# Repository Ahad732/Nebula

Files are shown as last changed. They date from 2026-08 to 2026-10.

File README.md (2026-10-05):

# RP2040 Devboard
I have made a devboard with RP 2040 microcontroller. It has 16 mb storage and its just like a raspberry pi pico but in my design. I had build it off a guide from macondo.I built it to learn hardware. This was my first hardware project for hackclub. It has a usb type C port that is used everywhere nowadays.

Features :
16 Mbit Storage    
Bootsel button  
Uses the popular RP2040 microcontroller    
Can be easily coded for custom projects and inovative ideas  
Open-source so anyone can use the design and order their board  
Has 2 leds, a power and a gpio led  

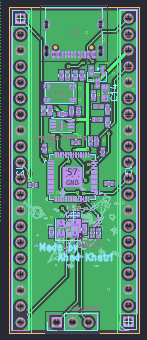
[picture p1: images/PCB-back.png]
  
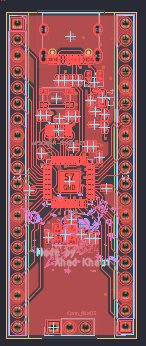
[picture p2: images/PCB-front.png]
  
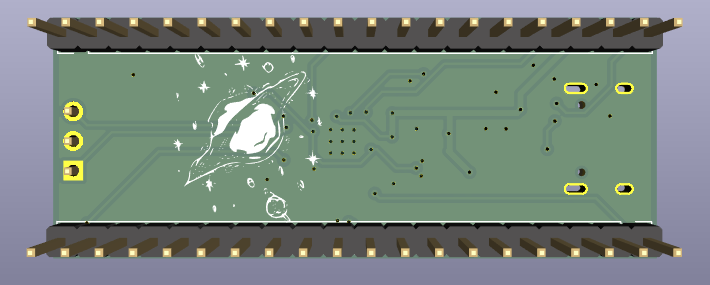
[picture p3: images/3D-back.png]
 
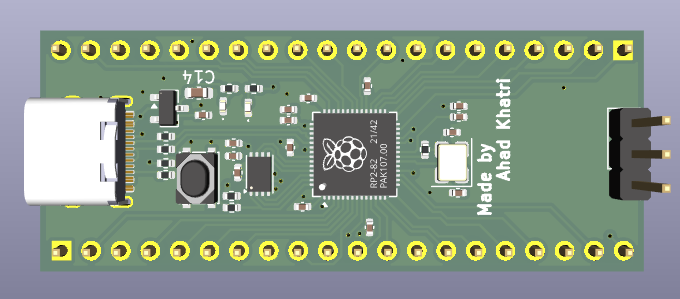
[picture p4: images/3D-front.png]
 
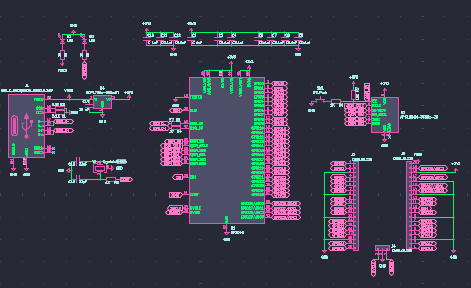
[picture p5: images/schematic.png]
schematic


|Designator |Footprint |Value |Quantity |Price |Link |
|---|---|---|---|---|---|
|C1_2, C1, C10 |402 |C 1uf |125 |0.1 |https://robu.in/product/cl05a105kq5nnwc-samsung-electro-mechanics-multilayer-ceramic-capacitors-mlcc-smd-smt-1uf-10-6-3v-x5r-1-0402/ |
|C11, C12, C3, C4, C5, C6, C7, C8, C9_2, C9|402 |C0.1uf |ALREADY HAVE |---------------------|https://robu.in/product/0402b104j100ct-walsin-smd-multilayer-ceramic-capacitor-general-purpose-0-1-%c2%b5f-10-v-0402-1005-metric-%c2%b1-5-x7r/ |
|C14 |603 |10 uF |ALREADY HAVE |---------------------|https://robu.in/product/tcc0603x5r106m100ct-cctc-smt-ceramic-capacitors-0603-x5r-106m10%c2%b5f%c2%b120-rated-voltage10v-thickness0-80mm-tape/ |
|C15, C16 |402 |33pF |30 |0.11 |https://robu.in/product/0402hq330j500nb-fh-smd-multilayer-ceramic-capacitor-33-pf-50-v-0402-1005-metric-%c2%b1-5-c0g/ |
|J1 |USB_C_Receptacle_XKB_U262-16XN-4BVC11 |USB_C_Receptacle_USB2.0_16P|ALREADY HAVE |---------------------|https://www.lcsc.com/product-detail/C393939.html?s_z=n_q_c393939&globalKeyword=c393939 |
|J2, J3 |PinHeader_1x20_P2.54mm_Vertical |Conn_01x20 |2 |DNP | |
|J4 |PinHeader_1x03_P2.54mm_Vertical |Conn_01x03 |1 |DNP | |
|R1, R2 |402 |5.1K |100 |0.11 |https://robu.in/product/rc0402fr-075k1l-yageo-smd-chip-resistor/ |
|R3, R4 |402 |27 |35 |0.12 |https://robu.in/product/0402wgj0270tce-uniohm-royal-ohm-62-5mw-thick-film-resistors-50v%c2%b1100ppm-%e2%84%83-%c2%b15-27%cf%89-0402-chip-resistor-surface-mount-rohs/|
|R5, R6, R7, R8 |402 |1K |30 |0.11 |https://robu.in/product/wr04x1001ftl-walsin-62-5mw-thick-film-resistors-50v-%c2%b1100ppm-%e2%84%83-%c2%b11-1k%cf%89-0402-chip-resistor-surface-mount-rohs/ |
|R7 |402 |10K |85 |0.11 |https://robu.in/product/rc0402fr-0710kl-yageo-res-thick-film-0402-10k-ohm-1-0-063w1-16w-%c2%b1100ppm-c-pad-smd-t-r/ |
|SW1 |Button_Switch_SMD:SW_SPST_PTS810 |SW_Push |5 |0.99 |https://robu.in/product/pts810sjg250smtrlfs-ck-3-2mm-2-5mm-round-button-50ma-standing-paste-4-2mm-spst-400gf-16v-smd-4p3-2x4-2mm-tactile-switches-rohs/ |
|U1 |QFN-56-1EP_7x7mm_P0.4mm_EP3.2x3.2mm |RP2040 |2 |1.33 |https://robu.in/product/raspberry-pi-rp2040/ |
|U2 |Winbond_USON-8-1EP_3x2mm_P0.5mm_EP0.2x1.6mm|APS1604M-3SQRx-ZR |2 |4.88 |https://www.lioncircuits.com/parts/IS25WP016D-JULE-TR |
|U4 |SOT-23 |MCP1700x-330xxTT |2 |1.05 |https://www.lioncircuits.com/parts/MCP1700T-3302E%2FTT |
|Y1 |Crystal_SMD_3225-4Pin_3.2x2.5mm |Crystal_GND24 |2 |1.23 |https://www.lioncircuits.com/parts/ECS-120-20-33-CKM-TR |
|D1, D2 |Led |402 |---------------------- |ALREADY HAVE |--------------------- |
| | | |Tools Required For Building|22.88 |https://robu.in/product/yihua-8858-v-hot-air-station-nozzles-stand/ |
| | | |PCB Cost + Shipping |9.29 | |
| | | |Parts Shipping |1.55 | |
| | | |Total |43.86 | |

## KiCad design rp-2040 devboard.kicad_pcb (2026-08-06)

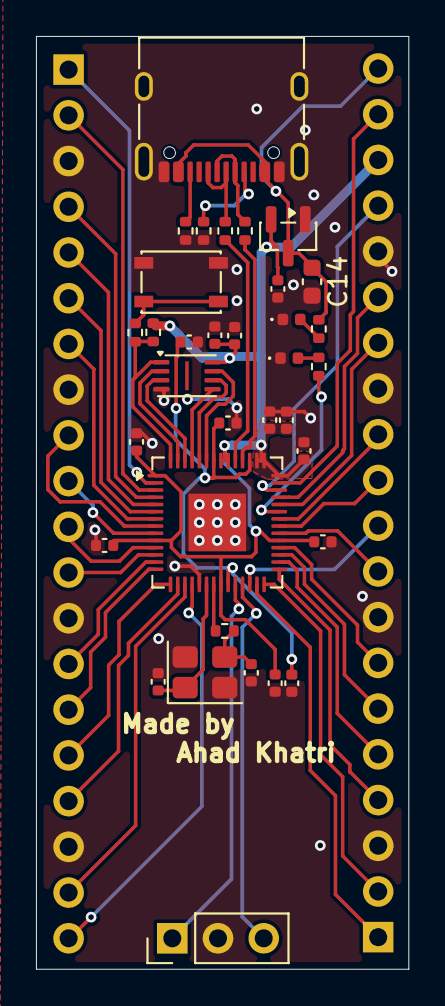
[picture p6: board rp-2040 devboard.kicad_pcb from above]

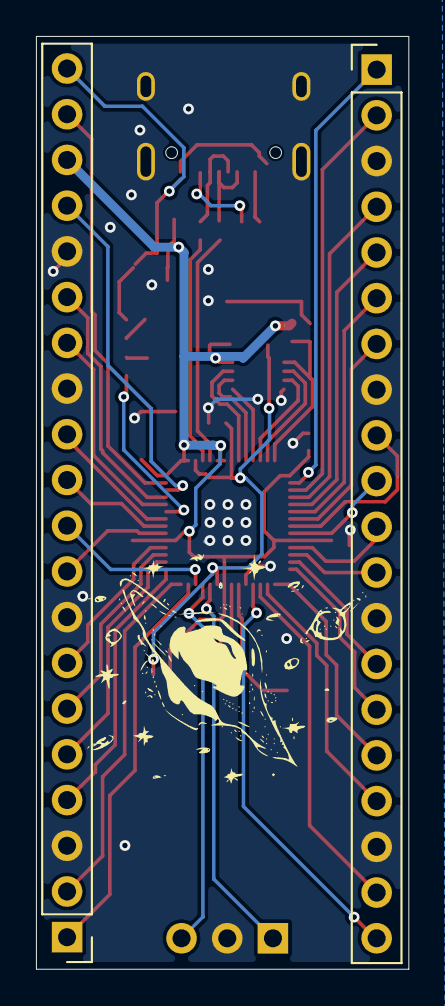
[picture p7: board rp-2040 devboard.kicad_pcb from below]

Board: 2 copper layers, 20.7 x 51.8 mm, 36 parts (2 on the bottom side), 55 nets.

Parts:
C1, C1#2, C10: C 1uf; C_0402_1005Metric
C3, C4, C5, C6, C7, C8, C9, C9#2, C11, C12: C0.1uf; C_0402_1005Metric
C14: 10 uF; C_0603_1608Metric
C15, C16: 33pF; C_0402_1005Metric
D1, D2: LED; LED_0402_1005Metric
J1: USB_C_Receptacle_USB2.0_16P; USB_C_Receptacle_XKB_U262-16XN-4BVC11
J2, J3: Conn_01x20; PinHeader_1x20_P2.54mm_Vertical
J4: Conn_01x03; PinHeader_1x03_P2.54mm_Vertical
R1, R2: 5.1K; R_0402_1005Metric
R3, R4: 27; R_0402_1005Metric
R5, R6, R8, R9: 1K; R_0402_1005Metric
R7: 10K; R_0402_1005Metric
SW1: SW_Push; SW_SPST_PTS810
U1: RP2040; QFN-56-1EP_7x7mm_P0.4mm_EP3.2x3.2mm
U2: APS1604M-3SQRx-ZR; Winbond_USON-8-1EP_3x2mm_P0.5mm_EP0.2x1.6mm
U4: MCP1700x-330xxTT; SOT-23
Y1: Crystal_GND24; Crystal_SMD_3225-4Pin_3.2x2.5mm

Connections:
+1V1: C10.1, C11.1, C12.1, U1.23 (DVDD), U1.45 (VREG_VOUT), U1.50 (DVDD)
+3V3: C1.1, C1#2.1, C3.1, C4.1, C5.1, C6.1, C7.1, C8.1, C9.1, C9#2.1, J3.18, R7.2, U1.1 (IOVDD), U1.10 (IOVDD), U1.22 (IOVDD), U1.33 (IOVDD), U1.42 (IOVDD), U1.43 (ADC_AVDD), U1.44 (VREG_VIN), U1.48 (USB_VDD), U1.49 (IOVDD), U2.8 (VDD), U4.2 (VO)
GND: C1.2, C1#2.2, C3.2, C4.2, C5.2, C6.2, C7.2, C8.2, C9.2, C9#2.2, C10.2, C11.2, C12.2, C14.2, C15.1, C16.1, D1.1 (K), D2.1 (K), J1.A1 (GND), J1.A12 (GND), J1.B1 (GND), J1.B12 (GND), J1.SH (SHIELD), J2.3, J2.8, J2.13, J2.18, J3.3, J3.8, J3.13, J3.16, J4.2, R1.1, R2.1, SW1.1, U1.19 (TESTEN), U1.57 (GND), U2.4 (VSS), U4.1 (GND), Y1.2 (G), Y1.4 (G)
GPIO0: J2.1, U1.2 (GPIO0)
GPIO1: J2.2, U1.3 (GPIO1)
GPIO2: J2.4, U1.4 (GPIO2)
GPIO3: J2.5, U1.5 (GPIO3)
GPIO4: J2.6, U1.6 (GPIO4)
GPIO5: J2.7, U1.7 (GPIO5)
GPIO6: J2.9, U1.8 (GPIO6)
GPIO7: J2.10, U1.9 (GPIO7)
GPIO8: J2.11, U1.11 (GPIO8)
GPIO9: J2.12, U1.12 (GPIO9)
GPIO10: J2.14, U1.13 (GPIO10)
GPIO11: J2.15, U1.14 (GPIO11)
GPIO12: J2.16, U1.15 (GPIO12)
GPIO13: J2.17, U1.16 (GPIO13)
GPIO14: J2.19, U1.17 (GPIO14)
GPIO15: J2.20, U1.18 (GPIO15)
GPIO16: J3.1, U1.27 (GPIO16)
GPIO17: J3.2, U1.28 (GPIO17)
GPIO18: J3.4, U1.29 (GPIO18)
GPIO19: J3.5, U1.30 (GPIO19)
GPIO20: J3.6, U1.31 (GPIO20)
GPIO21: J3.7, U1.32 (GPIO21)
GPIO22: J3.9, U1.34 (GPIO22)
GPIO23: J3.11, U1.35 (GPIO23)
GPIO24: J3.12, U1.36 (GPIO24)
GPIO25: R9.1, U1.37 (GPIO25)
GPIO26/ADC0: J3.14, U1.38 (GPIO26/ADC0)
GPIO27/ADC1: J3.15, U1.39 (GPIO27/ADC1)
GPIO28/ADC2: J3.17, U1.40 (GPIO28/ADC2)
GPIO29/ADC3: J3.19, U1.41 (GPIO29/ADC3)
unnamed: C15.2, R5.1, Y1.3
unnamed: D1.2 (A), R8.2
unnamed: D2.2 (A), R9.2
unnamed: J1.A5 (CC1), R2.2
unnamed: J1.B5 (CC2), R1.2
unnamed: R6.1, SW1.2
unnamed: R3.1, U1.46 (USB_DM)
unnamed: R4.1, U1.47 (USB_DP)
QSPI_SCLK: U1.52 (QSPI_SCLK), U2.6 (SCLK)
QSPI_SD0: U1.53 (QSPI_SD0), U2.5 (SI/SIO0)
QSPI_SD1: U1.55 (QSPI_SD1), U2.2 (SO/SIO1)
QSPI_SD2: U1.54 (QSPI_SD2), U2.3 (SIO2)
QSPI_SD3: U1.51 (QSPI_SD3), U2.7 (SIO3)
QSPI_SS: R6.2, R7.1, U1.56 (~QSPI_SS), U2.1 (~CE)
RUN: J3.10, U1.26 (RUN)
SWCLK: J4.1, U1.24 (SWCLK)
SWDIO: J4.3, U1.25 (SWDIO)
USB_D+: J1.A6 (D+), J1.B6 (D+), R4.2
USB_D-: J1.A7 (D-), J1.B7 (D-), R3.2
VBUS: C14.1, J1.A4 (VBUS), J1.A9 (VBUS), J1.B4 (VBUS), J1.B9 (VBUS), J3.20, R8.1, U4.3 (VI)
XIN: C16.2, U1.20 (XIN), Y1.1
XOUT: R5.2, U1.21 (XOUT)

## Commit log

2026-07-18 new BOM
    [BOM.csv - Sheet1.csv, bom.csv, rp-2040 devboard.kicad_pcb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]
2026-08-04 Chnaged location of BOM
    [BOM.csv]
2026-08-06 Addded BOM to readme
    [DEVBOARD.step]
2026-08-06 Added BOM to readme
    [rp-2040 devboard.kicad_pcb, rp-2040 devboard.kicad_sch]
2026-08-06 Added new readme
    [rp-2040 devboard.kicad_pcb]
2026-08-06 changed PCB and Readme
    [DEVBOARD.step, designators.csv, positions.csv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]
2026-08-06 New readme
    [BOM.csv]
2026-08-06 added 3D models
    [rp-2040 devboard.kicad_pcb]
2026-08-06 removed unnecesary things
    [rp-2040 devboard.kicad_pcb, rp-2040 devboard.kicad_sch]
2026-10-05 Add open-source and LED information to README
